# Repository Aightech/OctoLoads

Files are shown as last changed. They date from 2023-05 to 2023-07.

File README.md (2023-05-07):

# OctoLoads: 8-Channel Load Cell Measurement PCB

OctoLoads is an 8-channel load cell measurement Printed Circuit Board (PCB) designed for projects that require simultaneous readings from multiple load cells. With 8 HX711 modules on a single board, it offers a practical and efficient solution for managing and synchronizing measurements across several load cells.

## Visualisation
Top             |  Bottom 
:-------------------------:|:-------------------------:
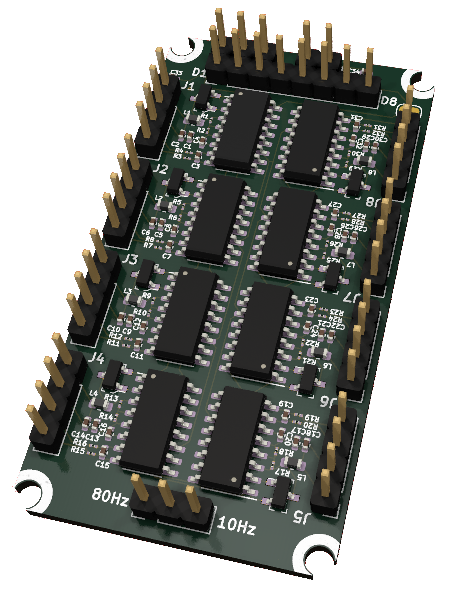
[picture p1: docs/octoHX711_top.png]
Top
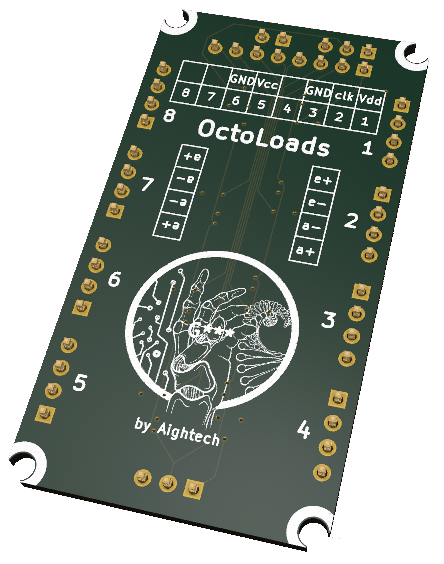
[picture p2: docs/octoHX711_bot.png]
Bop
 |  

## Features

    8 HX711 modules for measuring up to 8 load cells simultaneously
    Shared clock bus for perfectly synchronized measurements
    Selectable sampling rate: 10Hz or 80Hz
    Compatible with various load cells
    Optimized PCB layout for signal integrity, power distribution, and thermal management

## Applications

    Industrial weighing systems
    Multi-axis force/torque measurements
    Robotics and automation
    Agricultural and food processing equipment
    Fitness and sports equipment

## Getting Started

    Hardware Setup: Connect your load cells to the octoLoads board following the appropriate wiring diagram provided in the documentation.

    Sampling Rate Selection: Choose between the two available sampling rates (10Hz or 80Hz) by setting the jumper on the board as described in the documentation.

    Microcontroller Integration: Connect the octoLoads board to your microcontroller or processing unit, and utilize the provided library or API for seamless integration.

    Software Setup: Import the provided octoLoads library into your project, and follow the example code in the documentation to start taking measurements from your load cells.

## Documentation

Detailed documentation, including schematics, layout files, and instructions for use, is available in the docs folder.

## Support

For any questions or issues, please raise an issue'

## License
This project is licensed under the MIT License - see the LICENSE file for details.

## Code
### Building source code

To build the project run:
```bash
cd octoLoads
mkdir build && cd build
cmake .. && make
```

### Demonstration app

When the project have been built, you can run:
```bash
./octoLoads -h
```
to get the demonstration app usage.

### Example
Open the main.cpp file to get an example how to use the lib.

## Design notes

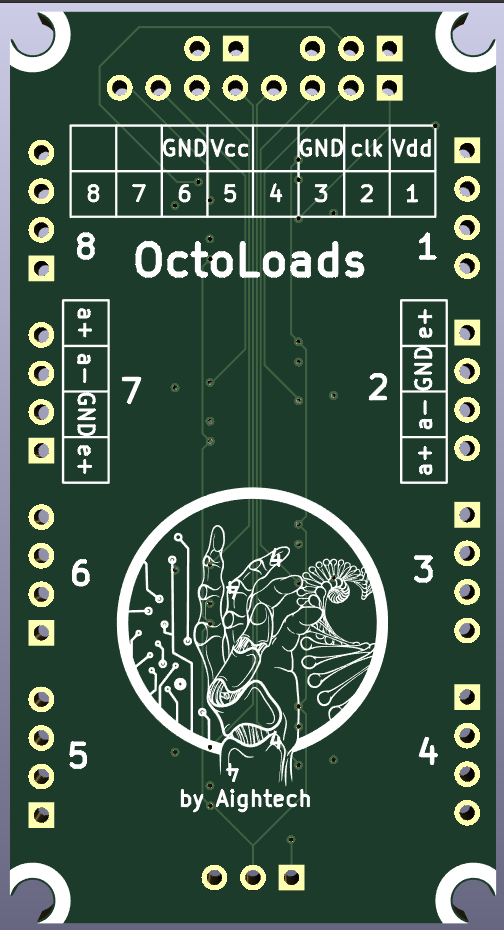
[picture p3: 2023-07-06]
docs/Screenshot from 2023-07-06 13-11-26.png

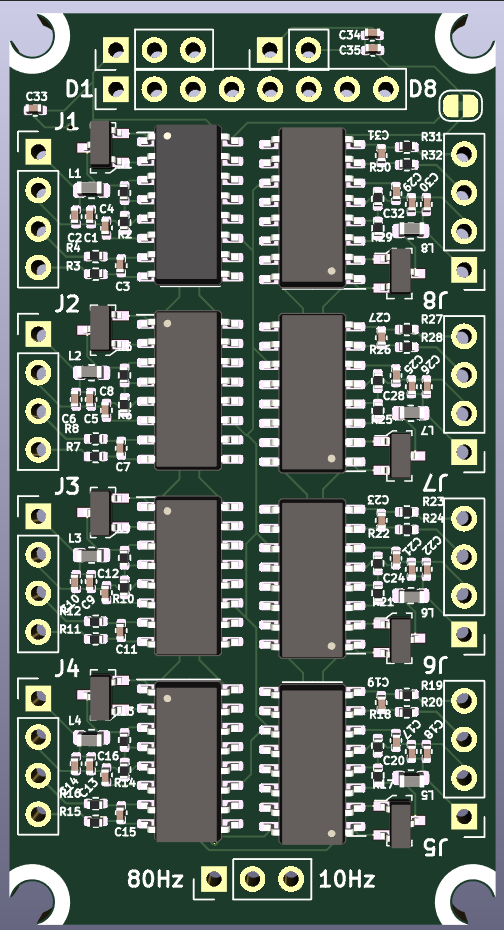
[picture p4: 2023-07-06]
docs/Screenshot from 2023-07-06 13-08-29.png

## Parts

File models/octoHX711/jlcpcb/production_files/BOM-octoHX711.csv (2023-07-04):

Comment | Designator | Footprint | LCSC
3.3uH | L1,L2,L3,L4,L5,L6,L7,L8 | L_0603_1608Metric | C139209
100nF | C1,C11,C12,C13,C15,C16,C17,C19,C20,C21,C23,C24,C25,C27,C28,C29,C3,C31,C32,C33,C34,C4,C5,C7,C8,C9 | C_0402_1005Metric | C1525
10uF | C10,C14,C18,C2,C22,C26,C30,C35,C6 | C_0402_1005Metric | C15525
100 | R11,R12,R15,R16,R19,R20,R23,R24,R27,R28,R3,R31,R32,R4,R7,R8 | R_0402_1005Metric | C25076
20k | R1,R13,R17,R21,R25,R29,R5,R9 | R_0402_1005Metric | C25765
8.2k | R10,R14,R18,R2,R22,R26,R30,R6 | R_0402_1005Metric | C25924
HX711 | U1,U2,U3,U4,U5,U6,U7,U8 | SOP-16_3.9x9.9mm_P1.27mm | C43656
MMBT4403LT1G | Q1,Q2,Q3,Q4,Q5,Q6,Q7,Q8 | SOT-23-3 | C78864

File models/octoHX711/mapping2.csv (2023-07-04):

Footprint | Part Value | LCSC Part
ADS1293CISQE | ADS1293CISQE-NOPB | C181260
C_0201_0603Metric | 1nF | C526941
C_0201_0603Metric | 1uF | C53067
C_0201_0603Metric | 4.7uF | C335103
C_0201_0603Metric | 10K | C106225
C_0201_0603Metric | 10M | C320452
C_0201_0603Metric | 22pF | C272881
C_0201_0603Metric | 51 | C320945
C_0201_0603Metric | 100nF | C66938
C_0402_1005Metric | 10uF | C15525
C_0402_1005Metric | 100nF | C1525
C_0402_1005Metric | 1nF | C1523
C_0402_1005Metric | 1uF | C52923
C_0402_1005Metric | 4.7uF | C23733
C_0402_1005Metric | 10K | C25744
C_0402_1005Metric | 10M | C26082
C_0402_1005Metric | 22pF | C1555
C_0402_1005Metric | 51 | C25125
L_0603_1608Metric | 3.3uH | C139209
QFN-20-1EP_3x3mm_P0.4mm_EP1.4x1.4mm | HC32L110C6UA | C493490
R_0402_1005Metric | 8.2k | C25924
R_0402_1005Metric | 20k | C25765
R_0402_1005Metric | 100 | C25076
SMD3225-4P | 4.096MHz | C255991
SOP-16_3.9x9.9mm_P1.27mm | HX711 | C43656
SOT-23-3 | MMBT4403LT1G | C78864
WS2812-2020 | WS2812-2020 | C965555
XF2J-1824-12A | XF2J-1824-12A | C397324

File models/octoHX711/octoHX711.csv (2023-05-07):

Id | Designator | Footprint | Quantity | Designation | Supplier and ref
1 | JP1 | SolderJumper-2_P1.3mm_Bridged_RoundedPad1.0x1.5mm | 1 | SolderJumper_2_Bridged
2 | C35,C30,C26,C22,C18,C14,C10,C6,C2 | C_0402_1005Metric | 9 | 10uF
3 | C34,C33,C32,C31,C29,C28,C27,C25,C24,C23,C21,C20,C19,C17,C16,C15,C13,C12,C11,C9,C8,C7,C5,C4,C1,C3 | C_0402_1005Metric | 26 | 0.1uF
4 | J12,J10 | PinHeader_1x03_P2.54mm_Vertical | 2 | Conn_01x03_Male
5 | U8,U7,U6,U5,U4,U3,U2,U1 | SOP-16_3.9x9.9mm_P1.27mm | 8 | HX711
6 | R32,R31,R28,R27,R24,R23,R20,R19,R16,R15,R12,R11,R8,R7,R3,R4 | R_01005_0402Metric | 16 | 100
7 | R30,R26,R22,R18,R14,R10,R6,R2 | R_01005_0402Metric | 8 | 8.2k
8 | R29,R25,R21,R17,R13,R9,R5,R1 | R_01005_0402Metric | 8 | 20k
9 | Q8,Q7,Q6,Q5,Q4,Q3,Q2,Q1 | SOT-23-3 | 8 | MMBT4403LT1G
10 | L8,L7,L6,L5,L4,L3,L2,L1 | L_0603_1608Metric | 8 | L
11 | J8,J7,J6,J5,J4,J3,J2,J1 | PinHeader_1x04_P2.54mm_Vertical | 8 | Conn_01x04_Male
12 | J9 | PinHeader_1x08_P2.54mm_Vertical | 1 | Conn_01x08_Male
13 | J11 | PinHeader_1x02_P2.54mm_Vertical | 1 | Conn_01x02_Male

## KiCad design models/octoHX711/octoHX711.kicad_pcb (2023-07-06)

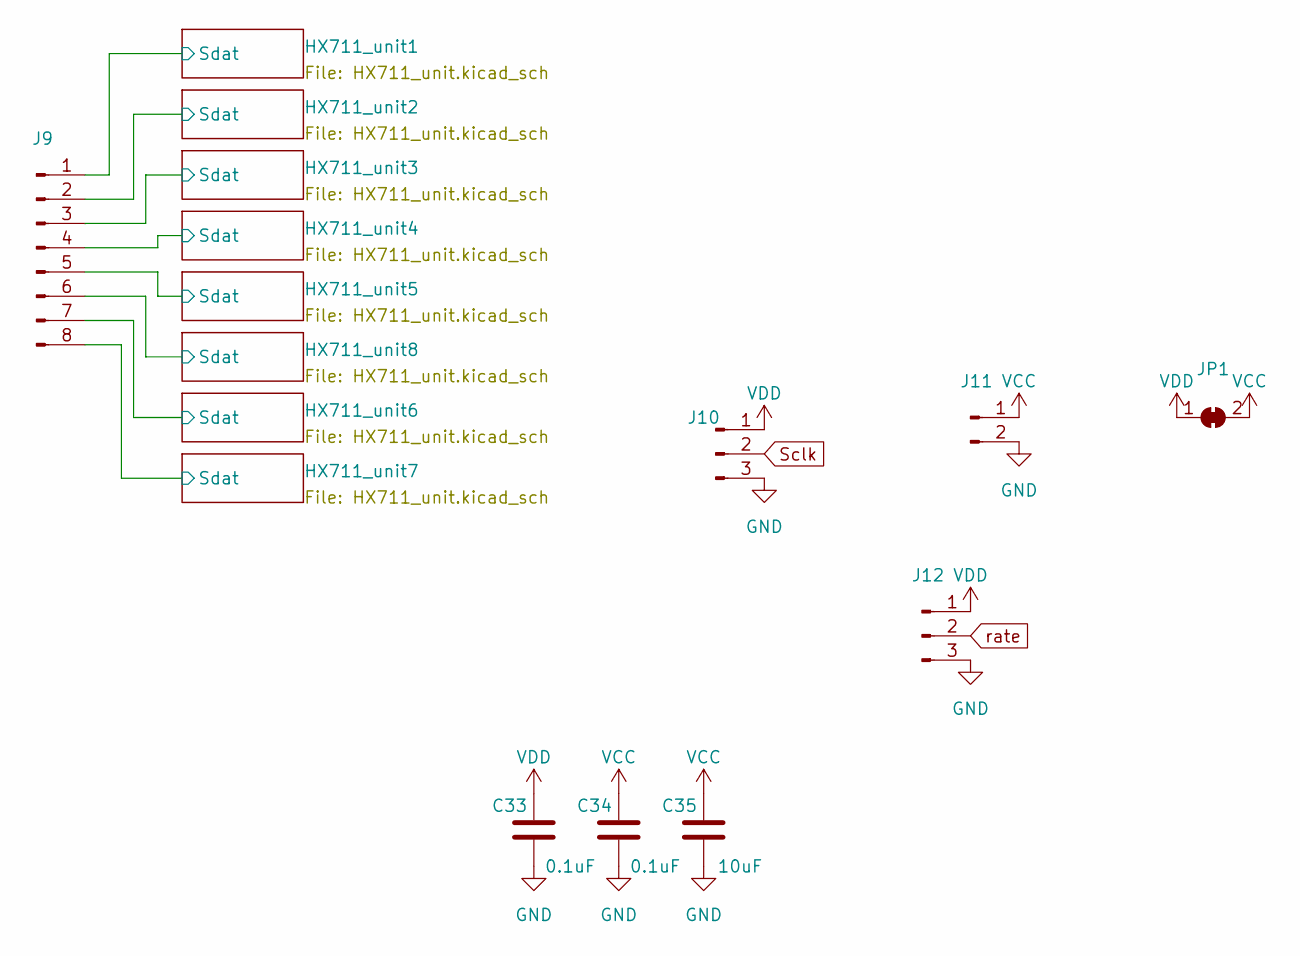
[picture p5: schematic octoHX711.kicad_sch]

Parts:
C33, C34: 0.1uF; C_0402_1005Metric
C35: 10uF; C_0402_1005Metric
J9: Conn_01x08_Male; PinHeader_1x08_P2.54mm_Vertical
J10, J12: Conn_01x03_Male; PinHeader_1x03_P2.54mm_Vertical
J11: Conn_01x02_Male; PinHeader_1x02_P2.54mm_Vertical
JP1: SolderJumper_2_Bridged; SolderJumper-2_P1.3mm_Bridged_RoundedPad1.0x1.5mm

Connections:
/HX711_unit1/Sdat: J9.1; also elsewhere on the board
/HX711_unit2/Sdat: J9.2; also elsewhere on the board
/HX711_unit3/Sdat: J9.3; also elsewhere on the board
/HX711_unit4/Sdat: J9.4; also elsewhere on the board
/HX711_unit5/Sdat: J9.5; also elsewhere on the board
/HX711_unit6/Sdat: J9.7; also elsewhere on the board
/HX711_unit7/Sdat: J9.8; also elsewhere on the board
/HX711_unit8/Sdat: J9.6; also elsewhere on the board
GND: C33.1, C34.1, C35.1, J10.3, J11.2, J12.3; also elsewhere on the board
Sclk: J10.2; also elsewhere on the board
VCC: C34.2, C35.2, J11.1, JP1.2 (B); also elsewhere on the board
VDD: C33.2, J10.1, J12.1, JP1.1 (A); also elsewhere on the board
rate: J12.2; also elsewhere on the board

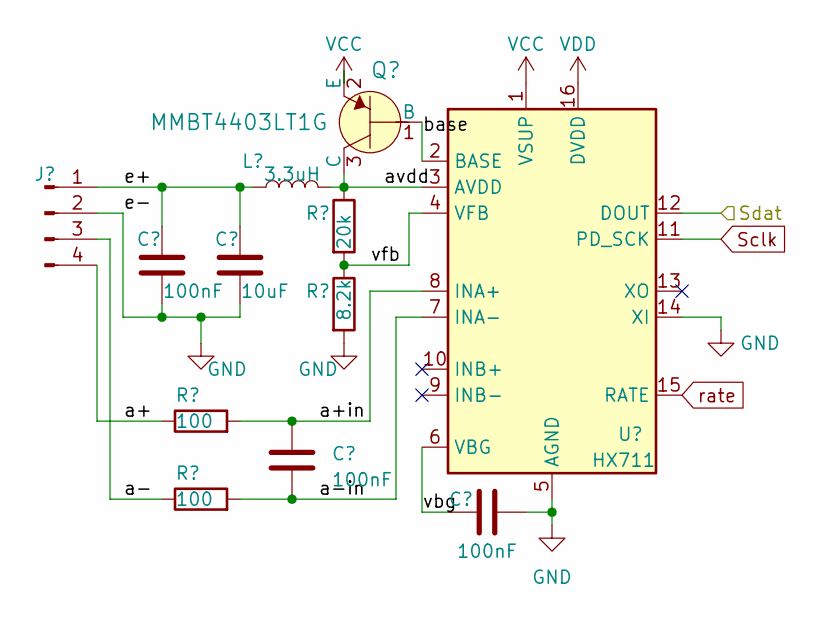
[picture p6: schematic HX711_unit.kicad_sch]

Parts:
C1, C3, C4: 100nF; C_0402_1005Metric
C2: 10uF; C_0402_1005Metric
J1: Conn_01x04_Male; PinHeader_1x04_P2.54mm_Vertical
L1: 3.3uH; L_0603_1608Metric
Q1: MMBT4403LT1G; SOT-23-3; MPN MMBT4403LT1G; Digi-Key_PN MMBT4403LT1GOSCT-ND
R1: 20k; R_0402_1005Metric
R2: 8.2k; R_0402_1005Metric
R3, R4: 100; R_0402_1005Metric
U1: HX711; SOP-16_3.9x9.9mm_P1.27mm

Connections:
/HX711_unit1/Sdat: U1.12 (DOUT); also elsewhere on the board
/HX711_unit1/a+: J1.4, R3.1
/HX711_unit1/a+in: C3.1, R3.2, U1.8 (INA+)
/HX711_unit1/a-: J1.3, R4.1
/HX711_unit1/a-in: C3.2, R4.2, U1.7 (INA-)
/HX711_unit1/avdd: L1.2, Q1.3 (C), R1.1, U1.3 (AVDD)
/HX711_unit1/base: Q1.1 (B), U1.2 (BASE)
/HX711_unit1/e+: C1.1, C2.1, J1.1, L1.1
/HX711_unit1/vbg: C4.1, U1.6 (VBG)
/HX711_unit1/vfb: R1.2, R2.1, U1.4 (VFB)
GND: C1.2, C2.2, C4.2, J1.2, R2.2, U1.5 (AGND), U1.14 (XI); also elsewhere on the board
Sclk: U1.11 (PD_SCK); also elsewhere on the board
VCC: Q1.2 (E), U1.1 (VSUP); also elsewhere on the board
VDD: U1.16 (DVDD); also elsewhere on the board
rate: U1.15 (RATE); also elsewhere on the board

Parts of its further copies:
C5, C7, C8, C9, C11, C12, C13, C15, C16, C17, C19, C20, C21, C23, C24, C25, C27, C28, C29, C31, C32: 100nF; C_0402_1005Metric
C6, C10, C14, C18, C22, C26, C30: 10uF; C_0402_1005Metric
J2, J3, J4, J5, J6, J7, J8: Conn_01x04_Male; PinHeader_1x04_P2.54mm_Vertical
L2, L3, L4, L5, L6, L7, L8: 3.3uH; L_0603_1608Metric
Q2, Q3, Q4, Q5, Q6, Q7, Q8: MMBT4403LT1G; SOT-23-3; MPN MMBT4403LT1G; Digi-Key_PN MMBT4403LT1GOSCT-ND
R5, R9, R13, R17, R21, R25, R29: 20k; R_0402_1005Metric
R6, R10, R14, R18, R22, R26, R30: 8.2k; R_0402_1005Metric
R7, R8, R11, R12, R15, R16, R19, R20, R23, R24, R27, R28, R31, R32: 100; R_0402_1005Metric
U2, U3, U4, U5, U6, U7, U8: HX711; SOP-16_3.9x9.9mm_P1.27mm

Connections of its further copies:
/HX711_unit2/Sdat: U2.12 (DOUT); also elsewhere on the board
/HX711_unit2/a+: J2.4, R7.1
/HX711_unit2/a+in: C7.1, R7.2, U2.8 (INA+)
/HX711_unit2/a-: J2.3, R8.1
/HX711_unit2/a-in: C7.2, R8.2, U2.7 (INA-)
/HX711_unit2/avdd: L2.2, Q2.3 (C), R5.1, U2.3 (AVDD)
/HX711_unit2/base: Q2.1 (B), U2.2 (BASE)
/HX711_unit2/e+: C5.1, C6.1, J2.1, L2.1
/HX711_unit2/vbg: C8.1, U2.6 (VBG)
/HX711_unit2/vfb: R5.2, R6.1, U2.4 (VFB)
/HX711_unit3/Sdat: U3.12 (DOUT); also elsewhere on the board
/HX711_unit3/a+: J3.4, R11.1
/HX711_unit3/a+in: C11.1, R11.2, U3.8 (INA+)
/HX711_unit3/a-: J3.3, R12.1
/HX711_unit3/a-in: C11.2, R12.2, U3.7 (INA-)
/HX711_unit3/avdd: L3.2, Q3.3 (C), R9.1, U3.3 (AVDD)
/HX711_unit3/base: Q3.1 (B), U3.2 (BASE)
/HX711_unit3/e+: C9.1, C10.1, J3.1, L3.1
/HX711_unit3/vbg: C12.1, U3.6 (VBG)
/HX711_unit3/vfb: R9.2, R10.1, U3.4 (VFB)
/HX711_unit4/Sdat: U4.12 (DOUT); also elsewhere on the board
/HX711_unit4/a+: J4.4, R15.1
/HX711_unit4/a+in: C15.1, R15.2, U4.8 (INA+)
/HX711_unit4/a-: J4.3, R16.1
/HX711_unit4/a-in: C15.2, R16.2, U4.7 (INA-)
/HX711_unit4/avdd: L4.2, Q4.3 (C), R13.1, U4.3 (AVDD)
/HX711_unit4/base: Q4.1 (B), U4.2 (BASE)
/HX711_unit4/e+: C13.1, C14.1, J4.1, L4.1
/HX711_unit4/vbg: C16.1, U4.6 (VBG)
/HX711_unit4/vfb: R13.2, R14.1, U4.4 (VFB)
/HX711_unit5/Sdat: U5.12 (DOUT); also elsewhere on the board
/HX711_unit5/a+: J5.4, R19.1
/HX711_unit5/a+in: C19.1, R19.2, U5.8 (INA+)
/HX711_unit5/a-: J5.3, R20.1
/HX711_unit5/a-in: C19.2, R20.2, U5.7 (INA-)
/HX711_unit5/avdd: L5.2, Q5.3 (C), R17.1, U5.3 (AVDD)
/HX711_unit5/base: Q5.1 (B), U5.2 (BASE)
/HX711_unit5/e+: C17.1, C18.1, J5.1, L5.1
/HX711_unit5/vbg: C20.1, U5.6 (VBG)
/HX711_unit5/vfb: R17.2, R18.1, U5.4 (VFB)
/HX711_unit6/Sdat: U7.12 (DOUT); also elsewhere on the board
/HX711_unit6/a+: J7.4, R27.1
/HX711_unit6/a+in: C27.1, R27.2, U7.8 (INA+)
/HX711_unit6/a-: J7.3, R28.1
/HX711_unit6/a-in: C27.2, R28.2, U7.7 (INA-)
/HX711_unit6/avdd: L7.2, Q7.3 (C), R25.1, U7.3 (AVDD)
/HX711_unit6/base: Q7.1 (B), U7.2 (BASE)
/HX711_unit6/e+: C25.1, C26.1, J7.1, L7.1
/HX711_unit6/vbg: C28.1, U7.6 (VBG)
/HX711_unit6/vfb: R25.2, R26.1, U7.4 (VFB)
/HX711_unit7/Sdat: U8.12 (DOUT); also elsewhere on the board
/HX711_unit7/a+: J8.4, R31.1
/HX711_unit7/a+in: C31.1, R31.2, U8.8 (INA+)
/HX711_unit7/a-: J8.3, R32.1
/HX711_unit7/a-in: C31.2, R32.2, U8.7 (INA-)
/HX711_unit7/avdd: L8.2, Q8.3 (C), R29.1, U8.3 (AVDD)
/HX711_unit7/base: Q8.1 (B), U8.2 (BASE)
/HX711_unit7/e+: C29.1, C30.1, J8.1, L8.1
/HX711_unit7/vbg: C32.1, U8.6 (VBG)
/HX711_unit7/vfb: R29.2, R30.1, U8.4 (VFB)
/HX711_unit8/Sdat: U6.12 (DOUT); also elsewhere on the board
/HX711_unit8/a+: J6.4, R23.1
/HX711_unit8/a+in: C23.1, R23.2, U6.8 (INA+)
/HX711_unit8/a-: J6.3, R24.1
/HX711_unit8/a-in: C23.2, R24.2, U6.7 (INA-)
/HX711_unit8/avdd: L6.2, Q6.3 (C), R21.1, U6.3 (AVDD)
/HX711_unit8/base: Q6.1 (B), U6.2 (BASE)
/HX711_unit8/e+: C21.1, C22.1, J6.1, L6.1
/HX711_unit8/vbg: C24.1, U6.6 (VBG)
/HX711_unit8/vfb: R21.2, R22.1, U6.4 (VFB)
GND: C5.2, C6.2, C8.2, C9.2, C10.2, C12.2, C13.2, C14.2, C16.2, C17.2, C18.2, C20.2, C21.2, C22.2, C24.2, C25.2, C26.2, C28.2, C29.2, C30.2, C32.2, J2.2, J3.2, J4.2, J5.2, J6.2, J7.2, J8.2, R6.2, R10.2, R14.2, R18.2, R22.2, R26.2, R30.2, U2.5 (AGND), U2.14 (XI), U3.5 (AGND), U3.14 (XI), U4.5 (AGND), U4.14 (XI), U5.5 (AGND), U5.14 (XI), U6.5 (AGND), U6.14 (XI), U7.5 (AGND), U7.14 (XI), U8.5 (AGND), U8.14 (XI); also elsewhere on the board
Sclk: U2.11 (PD_SCK), U3.11 (PD_SCK), U4.11 (PD_SCK), U5.11 (PD_SCK), U6.11 (PD_SCK), U7.11 (PD_SCK), U8.11 (PD_SCK); also elsewhere on the board
VCC: Q2.2 (E), Q3.2 (E), Q4.2 (E), Q5.2 (E), Q6.2 (E), Q7.2 (E), Q8.2 (E), U2.1 (VSUP), U3.1 (VSUP), U4.1 (VSUP), U5.1 (VSUP), U6.1 (VSUP), U7.1 (VSUP), U8.1 (VSUP); also elsewhere on the board
VDD: U2.16 (DVDD), U3.16 (DVDD), U4.16 (DVDD), U5.16 (DVDD), U6.16 (DVDD), U7.16 (DVDD), U8.16 (DVDD); also elsewhere on the board
rate: U2.15 (RATE), U3.15 (RATE), U4.15 (RATE), U5.15 (RATE), U6.15 (RATE), U7.15 (RATE), U8.15 (RATE); also elsewhere on the board

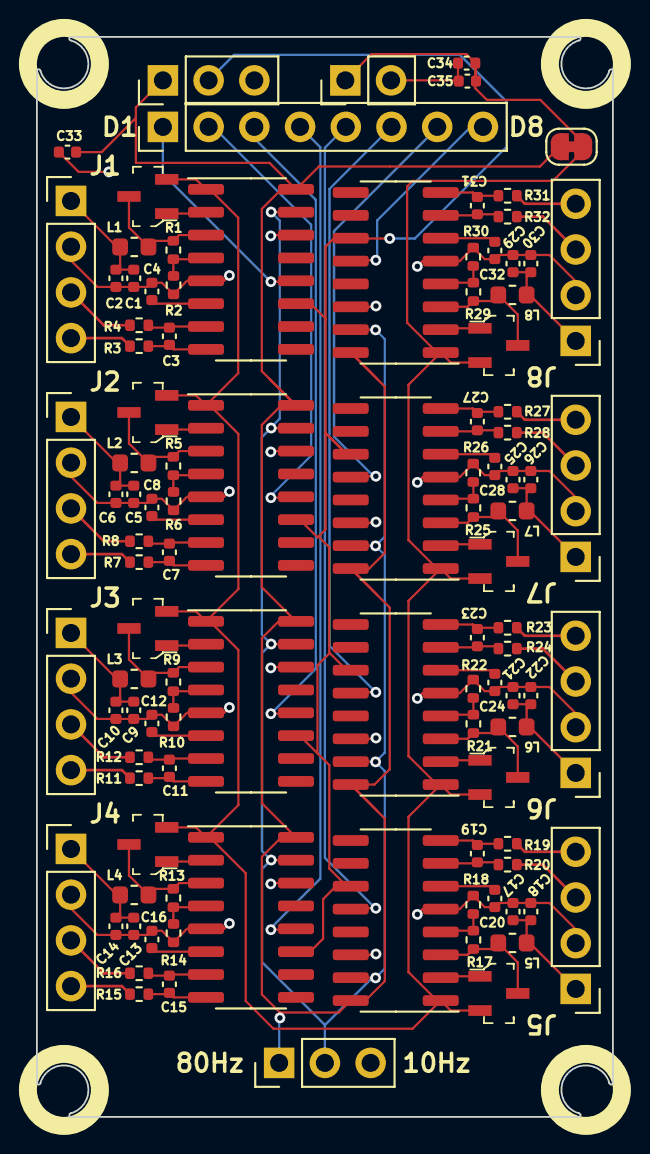
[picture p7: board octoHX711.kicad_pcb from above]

Board: 4 copper layers, 32.0 x 60.0 mm, 104 parts (0 on the bottom side), 85 nets.

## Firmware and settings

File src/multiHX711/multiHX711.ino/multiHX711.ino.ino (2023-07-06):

// Title: Multi HX711
// Author: Alexis Devillard
// Date: 27/11/22
// Description: Read simultaneously the data from 8 HX711 modules
//              connected to 22-29 on a mega2560. (need to change
//              the port registers reading if using an other board)
#include "HX711.hpp"
#define NB_LOADCELL 6
int hx711_data_pin[NB_LOADCELL] = { 22, 23, 24, 25, 26, 27 };
int32_t res[NB_LOADCELL] = { 0 };
int32_t offset[8] = { 0 };
const int sclk = 2;
int32_t val[NB_LOADCELL];

void setup() {
  Serial.begin(38400);
  pinMode(sclk, OUTPUT);
  pinMode(3, OUTPUT);
  pinMode(4, OUTPUT);
  digitalWrite(3,LOW);
  digitalWrite(4,LOW);
  for (int i = 0; i < NB_LOADCELL; i++)
    pinMode(hx711_data_pin[i], INPUT_PULLUP);

  int count = 0;
  for (int i = 0; i < NB_LOADCELL; i++) {
    offset[i] = 0;
    res[i] = 0;
  }
  while (count < 10) {
    if (read_8hx(res, hx711_data_pin, NB_LOADCELL, sclk)) {
      count++;
      for (int i = 0; i < NB_LOADCELL; i++)
        offset[i] += res[i];
    }
  }
  for (int i = 0; i < NB_LOADCELL; i++)
    offset[i] /= count;
}

void loop() {

  if (read_8hx(res, hx711_data_pin, NB_LOADCELL, sclk)) {
    for (uint8_t i = 0; i < NB_LOADCELL; i++) {
      Serial.print(res[i] - offset[i]);
      Serial.print(" ");
    }
    Serial.println("");
  }
  //delay(10);
}

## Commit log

2023-05-07 added img to readme
    [CMakeConfig.txt]
2023-07-04 fixed silkscreen and added arduino lib
    [BOM-octoHX711.csv, CMakeConfig.txt, HX711_unit.kicad_sch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]
